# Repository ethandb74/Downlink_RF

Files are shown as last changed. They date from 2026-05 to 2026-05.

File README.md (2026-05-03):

# Downlink_RF
4-layer PCB LoRa Puck:

This is a usb powereed LoRA Transmitter made for long range comnmunication with a programmable OLED display. This project was built around the SX1262 Radio chip and the RP2040 microcontroller. 
This project is inteded to be used as an alternative to using esp32 wireless communcation protocol (ESPNOW). this provides longer range and a seperate module making it a workaround to (in my experience) an often unrealiable communcation protocol. I learned the basics of RF pcb desing with the ultimiate goal of understanding all the systems of a cubeSat. This Satlite subsystem focus inspired the name Downlink. 

This Trasmitter is a 4 layer PCB

:
-      Fcu - singal 
 -     In1.cu - GND plane (Earth)
  -     In3.cu- +3V3 power plane
   -     Bcu- secondary signal

Main power for the module is delived via USB-C

RF: traces are routed at 0.1756mm width for 50ohm impedance  and IPD handels most of the Frontend with the exception of a pi circuit 

Frequency and Band 
--
This Puck transmits at 915Mhz or the ISM band
This band is license free and causes no issue with the FCC 

Schematic
--
orginized into sections with power/ memeory/ RF/ Microcontoller/ 



PCB
--
4-layer traces are routed at 0.1756mm width for 50ohm impedance no right angles tight via fencing around the RF section 



Kepp in mind the photo above is before some final iterations This is a 3d model of the Finished PCB:


BOM:
Attached is a link to the BOM with the individual Componants for the PCB
[Bom Link](BOM/Downlink_RF.csv)

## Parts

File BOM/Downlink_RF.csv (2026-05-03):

Id | Designator | Footprint | Quantity | Designation | Supplier and ref
1 | C12,C13 | C_0402_1005Metric | 2 | 1uF
2 | C14,C10,C18,C11,C23,C20,C19,C16,C2,C15,C1,C17 | C_0402_1005Metric | 12 | 100nF
3 | L2 | L_0402_1005Metric | 1 | 47nH
4 | AE1 | PinSocket_1x01_P2.54mm_Vertical | 1 | Antenna
5 | L1 | L_0402_1005Metric | 1 | 15uH
6 | R8,R7 | R_0402_1005Metric | 2 | 5.1K
7 | FL1 | Balun_Johanson_0900FM15K0039 | 1 | 0900FM15D0039001E
8 | R2,R3 | R_0402_1005Metric | 2 | 1K
9 | C6 | C_0402_1005Metric | 1 | 1nF
10 | C4 | C_0402_1005Metric | 1 | 47nF
11 | U5 | SOT-23-5 | 1 | AP2112K-3.3
12 | U1 | QFN-24-1EP_4x4mm_P0.5mm_EP2.6x2.6mm | 1 | SX1262IMLTRT
13 | R9,R10 | R_0402_1005Metric | 2 | 4.7K
14 | J1 | USB_C_Receptacle_GCT_USB4105-xx-A_16P_TopMnt_Horizontal | 1 | USB_C_Receptacle_USB2.0_16P
15 | L3 | L_0402_1005Metric | 1 | 9.1nH
16 | C3 | C_0402_1005Metric | 1 | 470nF
17 | C5 | C_0402_1005Metric | 1 | 47pF
18 | C24,C25 | C_0402_1005Metric | 2 | 10uF
19 | R1 | R_0402_1005Metric | 1 | 100
20 | Y1 | Crystal_SMD_3225-4Pin_3.2x2.5mm | 1 | 32MHz
21 | C21,C22 | C_0402_1005Metric | 2 | 15pF
22 | BOOTSEL | SW_Tactile_SPST_NO_Straight_CK_PTS636Sx25SMTRLFS | 1 | SW_Push
23 | J3 | PinSocket_1x04_P2.54mm_Vertical | 1 | Conn_01x04_Socket
24 | R5,R6 | R_0402_1005Metric | 2 | 27.4
25 | C7 | C_0402_1005Metric | 1 | 39pF
26 | U3 | SOT-363_SC-70-6 | 1 | PE4259
27 | R4 | R_0402_1005Metric | 1 | 10K
28 | FB1 | L_0402_1005Metric | 1 | BLM15AX102SN1D
29 | RESET | SW_Tactile_SPST_NO_Straight_CK_PTS636Sx25SMTRLFS | 1 | RESET
30 | U4 | SOIC-8_5.3x5.3mm_P1.27mm | 1 | W25Q128JVS
31 | C9,C8 | C_0402_1005Metric | 2 | 3.3pF
32 | Y2 | Crystal_SMD_Abracon_ABM8G-4Pin_3.2x2.5mm | 1 | 12MHz
33 | U2 | QFN-56-1EP_7x7mm_P0.4mm_EP3.2x3.2mm | 1 | RP2040

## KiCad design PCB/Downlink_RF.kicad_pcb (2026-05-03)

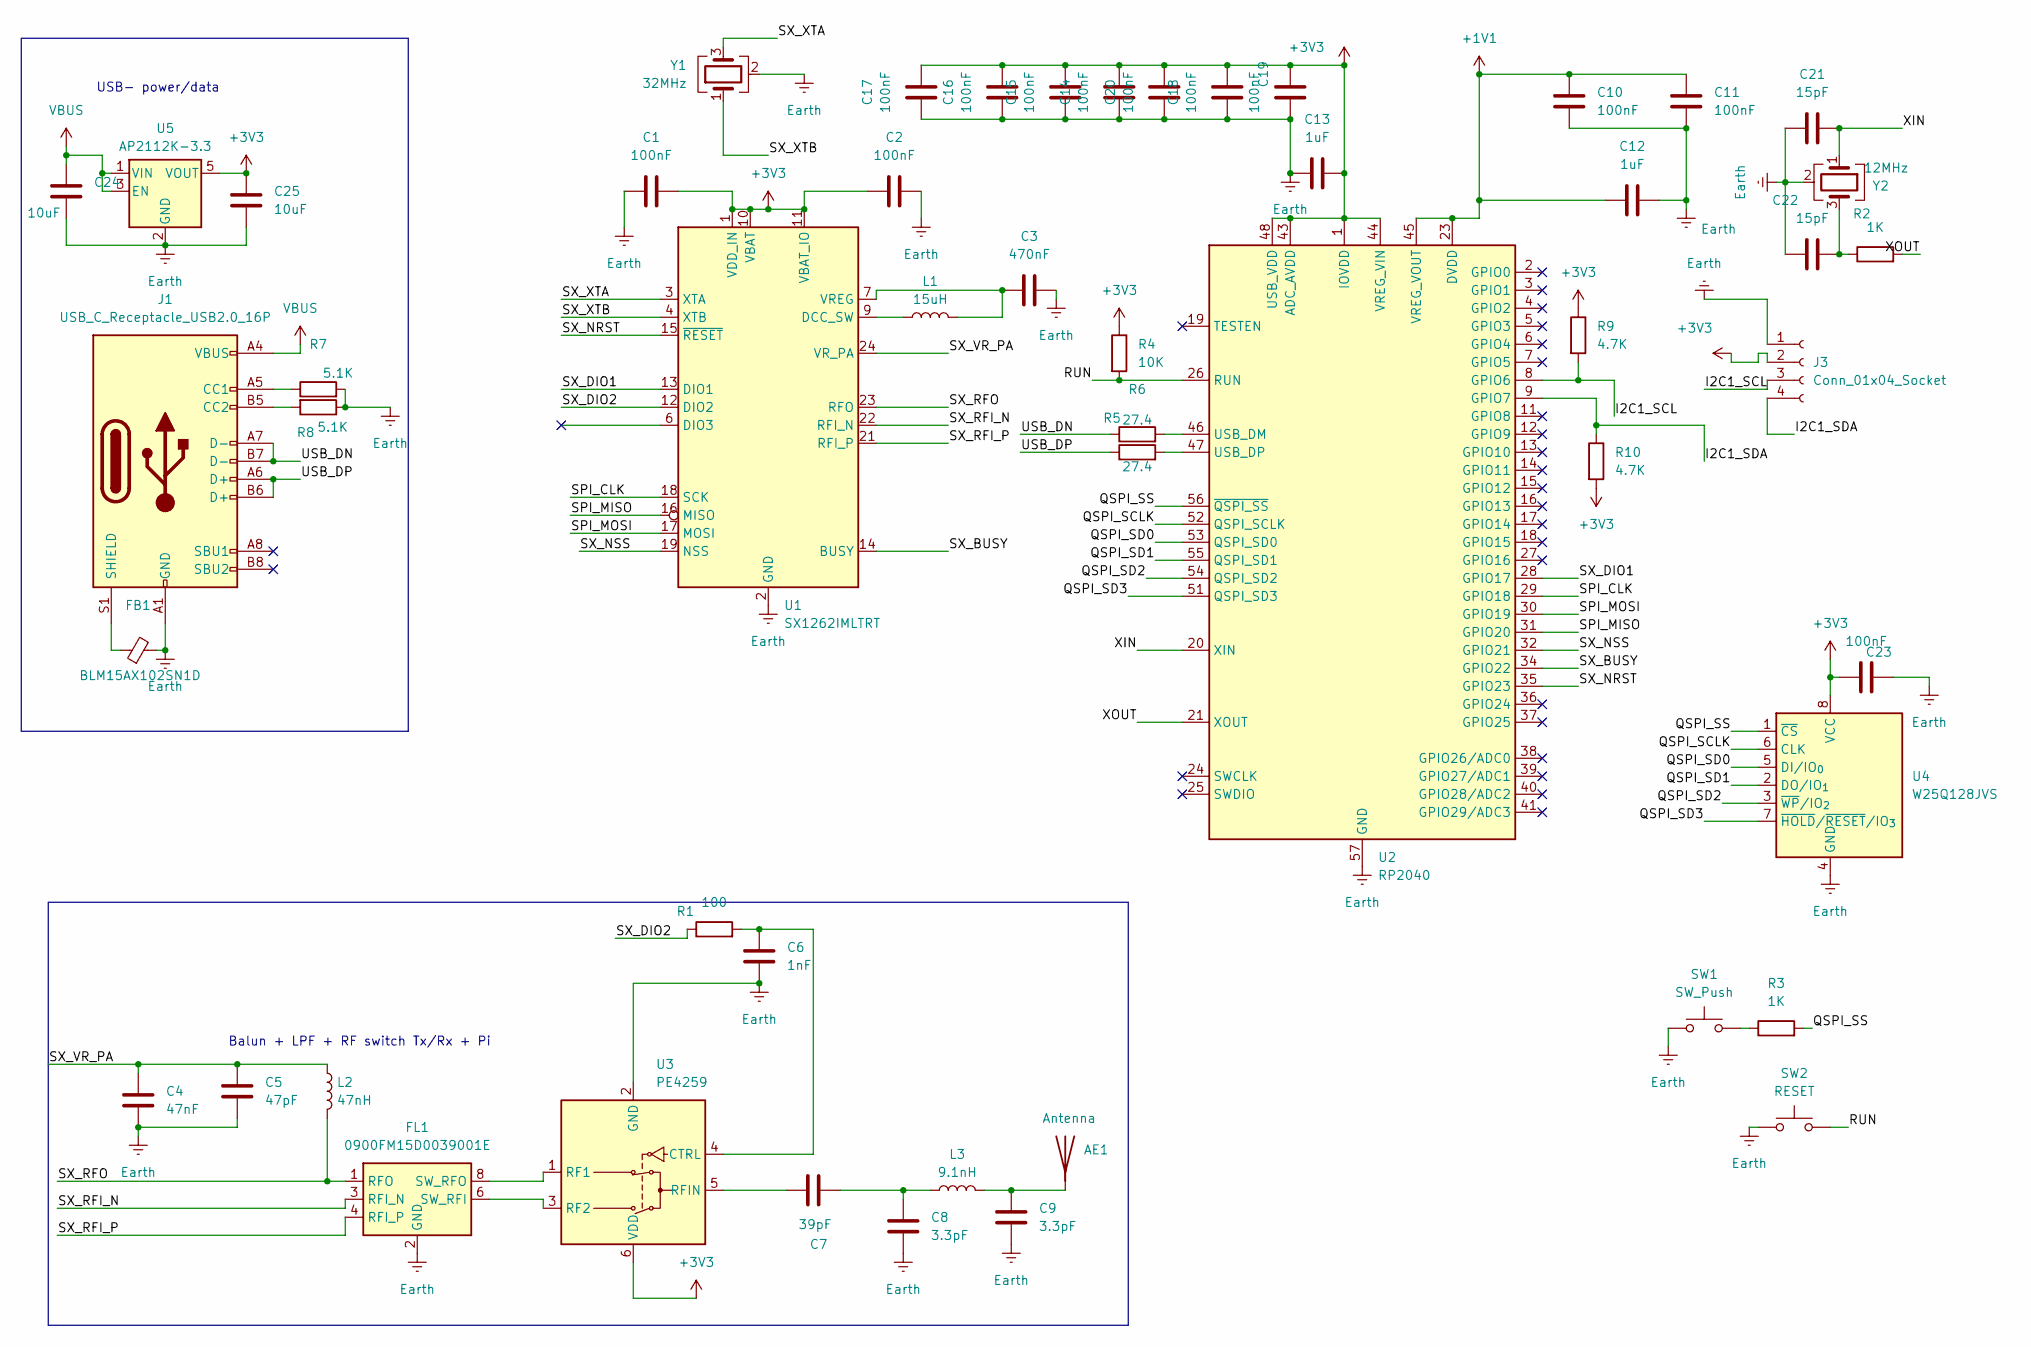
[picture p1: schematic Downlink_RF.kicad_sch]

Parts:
AE1: Antenna; PinSocket_1x01_P2.54mm_Vertical
C1, C2, C10, C11, C14, C15, C16, C17, C18, C19, C20, C23: 100nF; C_0402_1005Metric
C3: 470nF; C_0402_1005Metric
C4: 47nF; C_0402_1005Metric
C5: 47pF; C_0402_1005Metric
C6: 1nF; C_0402_1005Metric
C7: 39pF; C_0402_1005Metric
C8, C9: 3.3pF; C_0402_1005Metric
C12, C13: 1uF; C_0402_1005Metric
C21, C22: 15pF; C_0402_1005Metric
C24, C25: 10uF; C_0402_1005Metric
FB1: BLM15AX102SN1D; L_0402_1005Metric
FL1: 0900FM15D0039001E; Balun_Johanson_0900FM15K0039
J1: USB_C_Receptacle_USB2.0_16P; USB_C_Receptacle_GCT_USB4105-xx-A_16P_TopMnt_Horizontal
J3: Conn_01x04_Socket; PinSocket_1x04_P2.54mm_Vertical
L1: 15uH; L_0402_1005Metric
L2: 47nH; L_0402_1005Metric
L3: 9.1nH; L_0402_1005Metric
R1: 100; R_0402_1005Metric
R2, R3: 1K; R_0402_1005Metric
R4: 10K; R_0402_1005Metric
R5, R6: 27.4; R_0402_1005Metric
R7, R8: 5.1K; R_0402_1005Metric
R9, R10: 4.7K; R_0402_1005Metric
SW1: SW_Push; SW_Tactile_SPST_NO_Straight_CK_PTS636Sx25SMTRLFS
SW2: RESET; SW_Tactile_SPST_NO_Straight_CK_PTS636Sx25SMTRLFS
U1: SX1262IMLTRT; QFN-24-1EP_4x4mm_P0.5mm_EP2.6x2.6mm
U2: RP2040; QFN-56-1EP_7x7mm_P0.4mm_EP3.2x3.2mm
U3: PE4259; SOT-363_SC-70-6
U4: W25Q128JVS; SOIC-8_5.3x5.3mm_P1.27mm
U5: AP2112K-3.3; SOT-23-5
Y1: 32MHz; Crystal_SMD_3225-4Pin_3.2x2.5mm
Y2: 12MHz; Crystal_SMD_Abracon_ABM8G-4Pin_3.2x2.5mm

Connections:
+1V1: C10.2, C11.1, C12.2, U2.23 (DVDD), U2.45 (VREG_VOUT), U2.50 (DVDD)
+3V3: C1.2, C2.1, C13.2, C14.1, C15.1, C16.1, C17.1, C18.1, C19.1, C20.1, C23.1, C25.1, J3.2, R4.1, R9.1, R10.2, U1.1 (VDD_IN), U1.10 (VBAT), U1.11 (VBAT_IO), U2.1 (IOVDD), U2.10 (IOVDD), U2.22 (IOVDD), U2.33 (IOVDD), U2.42 (IOVDD), U2.43 (ADC_AVDD), U2.44 (VREG_VIN), U2.48 (USB_VDD), U2.49 (IOVDD), U3.6 (VDD), U4.8 (VCC), U5.5 (VOUT)
/I2C1_SCL: J3.3, R9.2, U2.8 (GPIO6)
/I2C1_SDA: J3.4, R10.1, U2.9 (GPIO7)
/QSPI_SCLK: U2.52 (QSPI_SCLK), U4.6 (CLK)
/QSPI_SD0: U2.53 (QSPI_SD0), U4.5 (DI/IO_{0})
/QSPI_SD1: U2.55 (QSPI_SD1), U4.2 (DO/IO_{1})
/QSPI_SD2: U2.54 (QSPI_SD2), U4.3 (~WP/IO_{2})
/QSPI_SD3: U2.51 (QSPI_SD3), U4.7 (~HOLD/~RESET/IO_{3})
/QSPI_SS: R3.2, U2.56 (~QSPI_SS), U4.1 (~CS)
/RUN: R4.2, SW2.2, U2.26 (RUN)
/SPI_CLK: U1.18 (SCK), U2.29 (GPIO18)
/SPI_MISO: U1.16 (MISO), U2.31 (GPIO20)
/SPI_MOSI: U1.17 (MOSI), U2.30 (GPIO19)
/SX_BUSY: U1.14 (BUSY), U2.34 (GPIO22)
/SX_DIO1: U1.13 (DIO1), U2.28 (GPIO17)
/SX_DIO2: R1.1, U1.12 (DIO2)
/SX_NRST: U1.15 (~RESET), U2.35 (GPIO23)
/SX_NSS: U1.19 (NSS), U2.32 (GPIO21)
/SX_RFI_N: FL1.3 (RFI_N), U1.22 (RFI_N)
/SX_RFI_P: FL1.4 (RFI_P), U1.21 (RFI_P)
/SX_RFO: FL1.1 (RFO), L2.2, U1.23 (RFO)
/SX_VR_PA: C4.1, C5.1, L2.1, U1.24 (VR_PA)
/SX_XTA: U1.3 (XTA), Y1.3
/SX_XTB: U1.4 (XTB), Y1.1
/USB_DN: J1.A7 (D-), J1.B7 (D-), R6.1
/USB_DP: J1.A6 (D+), J1.B6 (D+), R5.1
/XIN: C21.2, U2.20 (XIN), Y2.1
/XOUT: R2.2, U2.21 (XOUT)
Earth: C1.1, C2.2, C3.2, C4.2, C5.2, C6.2, C8.2, C9.2, C10.1, C11.2, C12.1, C13.1, C14.2, C15.2, C16.2, C17.2, C18.2, C19.2, C20.2, C21.1, C22.1, C23.2, C24.2, C25.2, FB1.2, FL1.2 (GND), FL1.5 (GND), FL1.7 (GND), FL1.9 (GND), FL1.10 (GND), J1.A1 (GND), J1.A12 (GND), J1.B1 (GND), J1.B12 (GND), J3.1, R7.2, R8.1, SW1.1, SW2.1, U1.2 (GND), U1.5 (GND), U1.8 (GND), U1.20 (GND), U1.25 (GND), U2.57 (GND), U3.2 (GND), U4.4 (GND), U5.2 (GND), Y1.2 (G), Y1.4 (G), Y2.2 (G), Y2.4 (G)
unnamed: AE1.1 (A), C9.1, L3.2
unnamed: C7.1, C8.1, L3.1
unnamed: C22.2, R2.1, Y2.3
unnamed: FL1.6 (SW_RFI), U3.3 (RF2)
unnamed: FL1.8 (SW_RFO), U3.1 (RF1)
unnamed: J1.A5 (CC1), R7.1
unnamed: J1.B5 (CC2), R8.2
unnamed: FB1.1, J1.S1 (SHIELD)
unnamed: R3.1, SW1.2
unnamed: L1.1, U1.9 (DCC_SW)
unnamed: C3.1, L1.2, U1.7 (VREG)
unnamed: R6.2, U2.46 (USB_DM)
unnamed: R5.2, U2.47 (USB_DP)
unnamed: C6.1, R1.2, U3.4 (CTRL)
unnamed: C7.2, U3.5 (RFIN)
VBUS: C24.1, J1.A4 (VBUS), J1.A9 (VBUS), J1.B4 (VBUS), J1.B9 (VBUS), U5.1 (VIN), U5.3 (EN)

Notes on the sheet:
Balun + LPF + RF switch Tx/Rx + Pi
USB- power/data

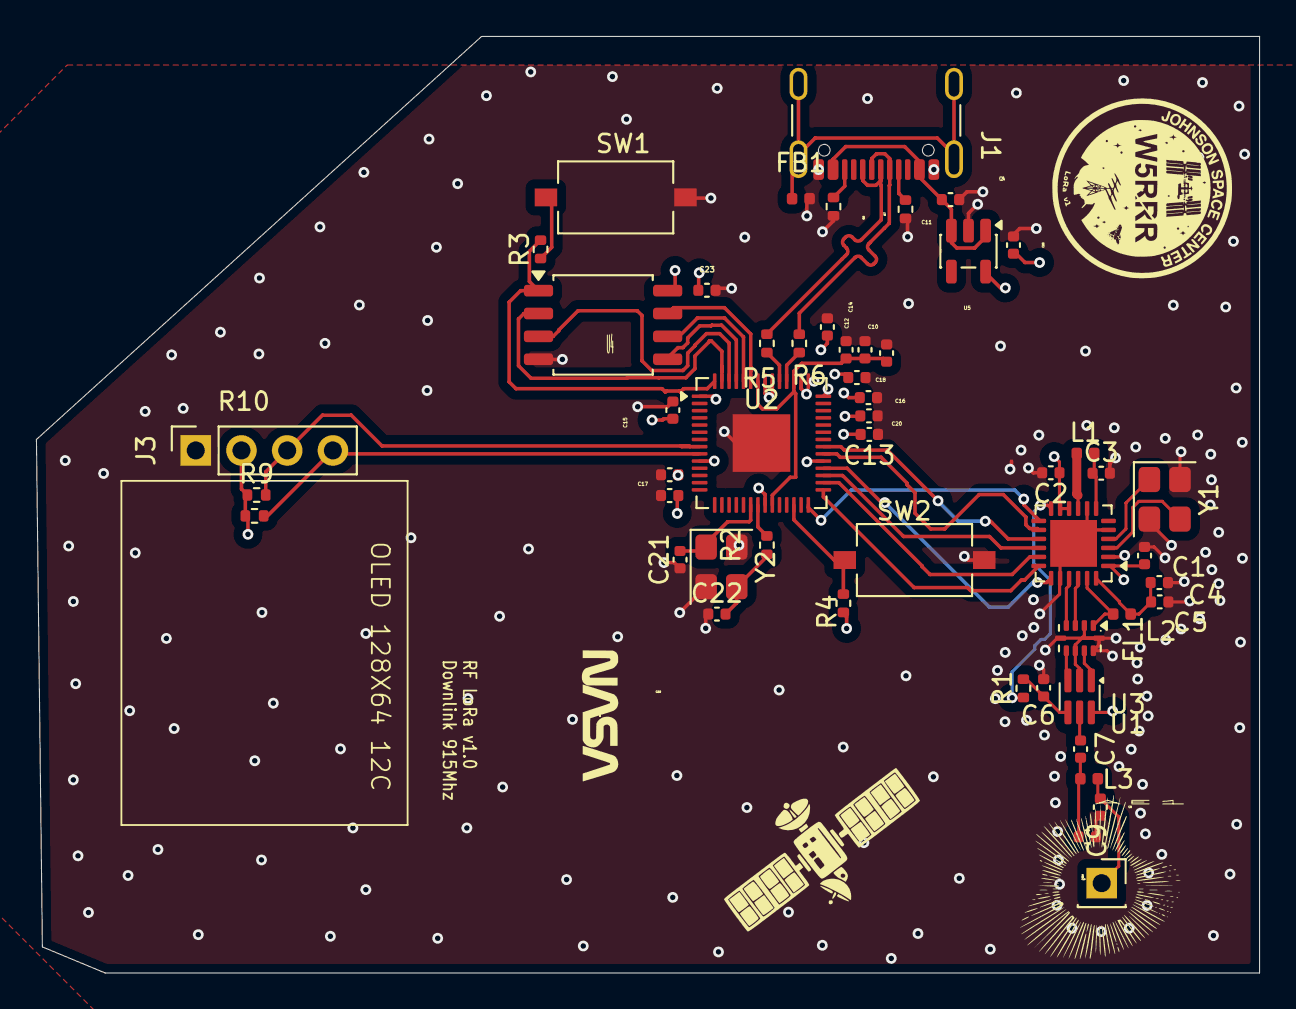
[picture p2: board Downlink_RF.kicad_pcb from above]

Board: 4 copper layers, 67.9 x 52.0 mm, 53 parts (0 on the bottom side), 46 nets.

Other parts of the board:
G**: LOGO; satlogo2
